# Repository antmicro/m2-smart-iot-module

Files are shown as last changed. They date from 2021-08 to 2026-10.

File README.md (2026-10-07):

# M.2 Smart IoT Module

Copyright (c) 2020-2026 [Antmicro](https://www.antmicro.com)

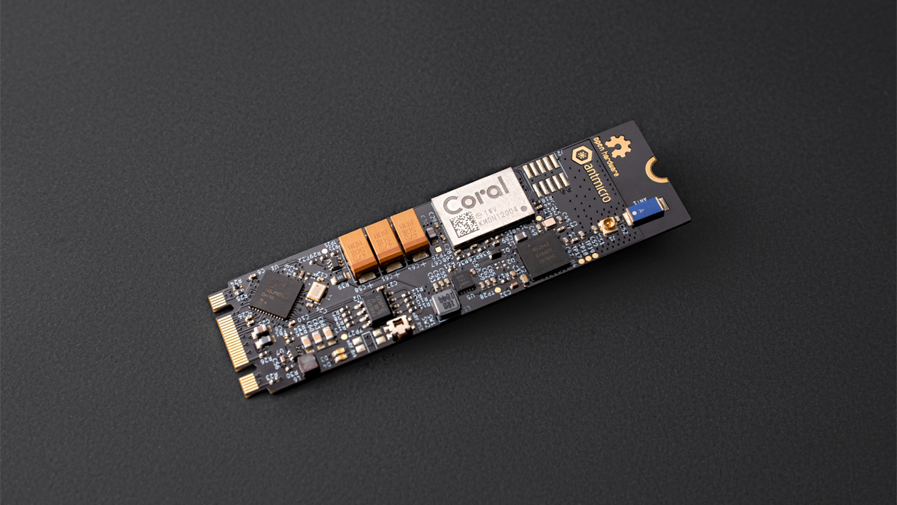
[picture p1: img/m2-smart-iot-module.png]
M.2 Smart IoT Module


## Overview

This project contains PCB design files of the smart IoT module in an M.2 form factor.
The module is an experimental platform that combines a programmable Nordic radio SoC with Google Coral Edge AI accelerator.
The design files were prepared in KiCad.

## Repository structure

The main repository directory contains KiCad PCB project files, a LICENSE and a README.
The remaining files are stored in the following directories:

* ``lib`` - contains the component libraries
* ``img`` - contains graphics for this README
* ``fab`` - contains overrides for board visualization

## Key Features

* Google Coral Edge TPU Accelerator Module
* Nordic Semiconductor nRF52840 Radio SoC
* On-board PCIe-USB bridge
* On-board FTDI chip for nRF52840 programming, debugging and serial communication
* M.2 key B+M form factor 
* 22 x 80 mm (0.87 x 3.15 inch) PCB outline

## License

[Apache-2.0](LICENSE)

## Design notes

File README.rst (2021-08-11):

====================
M.2 Smart IoT Module
====================

Copyright (c) 2020-2021 `Antmicro <https://www.antmicro.com>`_



Overview
--------

This repository contains design files of the smart IoT module in an M.2 form factor.
The module is an experimental platform that combines a programmable Nordic radio SoC with Google Coral Edge AI accelerator.
The design files were prepared in KiCad.
An initial production release for the design was fabricated as prototypes and these are now being tested.

Repository structure
--------------------
The main repository directory contains KiCad PCB project files, a LICENSE and README.
The remaining files are stored in the following directories:

* ``lib`` - contains the component libraries
* ``img`` - contains graphics for this README

Key Features
------------

* M.2 key B+M form factor 
* on-board PCIe-USB bridge
* Nordic Semiconductor nRF52840 Radio SoC
* Google Coral Edge TPU Accelerator Module

Block diagram
-------------

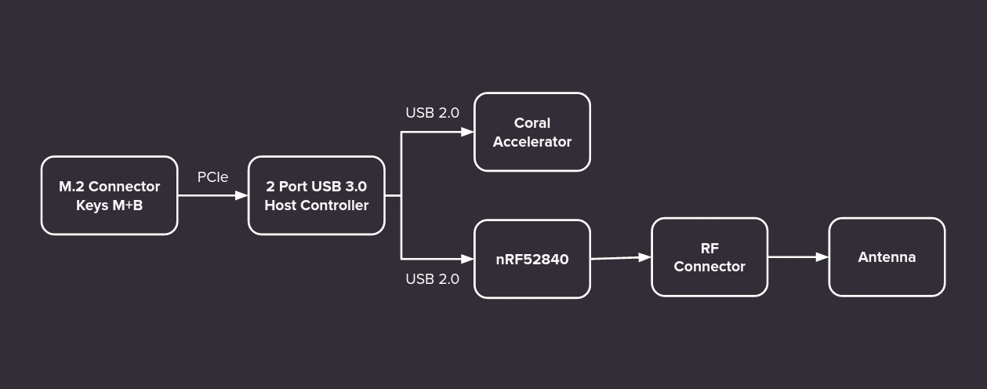
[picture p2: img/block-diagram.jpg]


License
=======

`Apache-2.0 <LICENSE>`_

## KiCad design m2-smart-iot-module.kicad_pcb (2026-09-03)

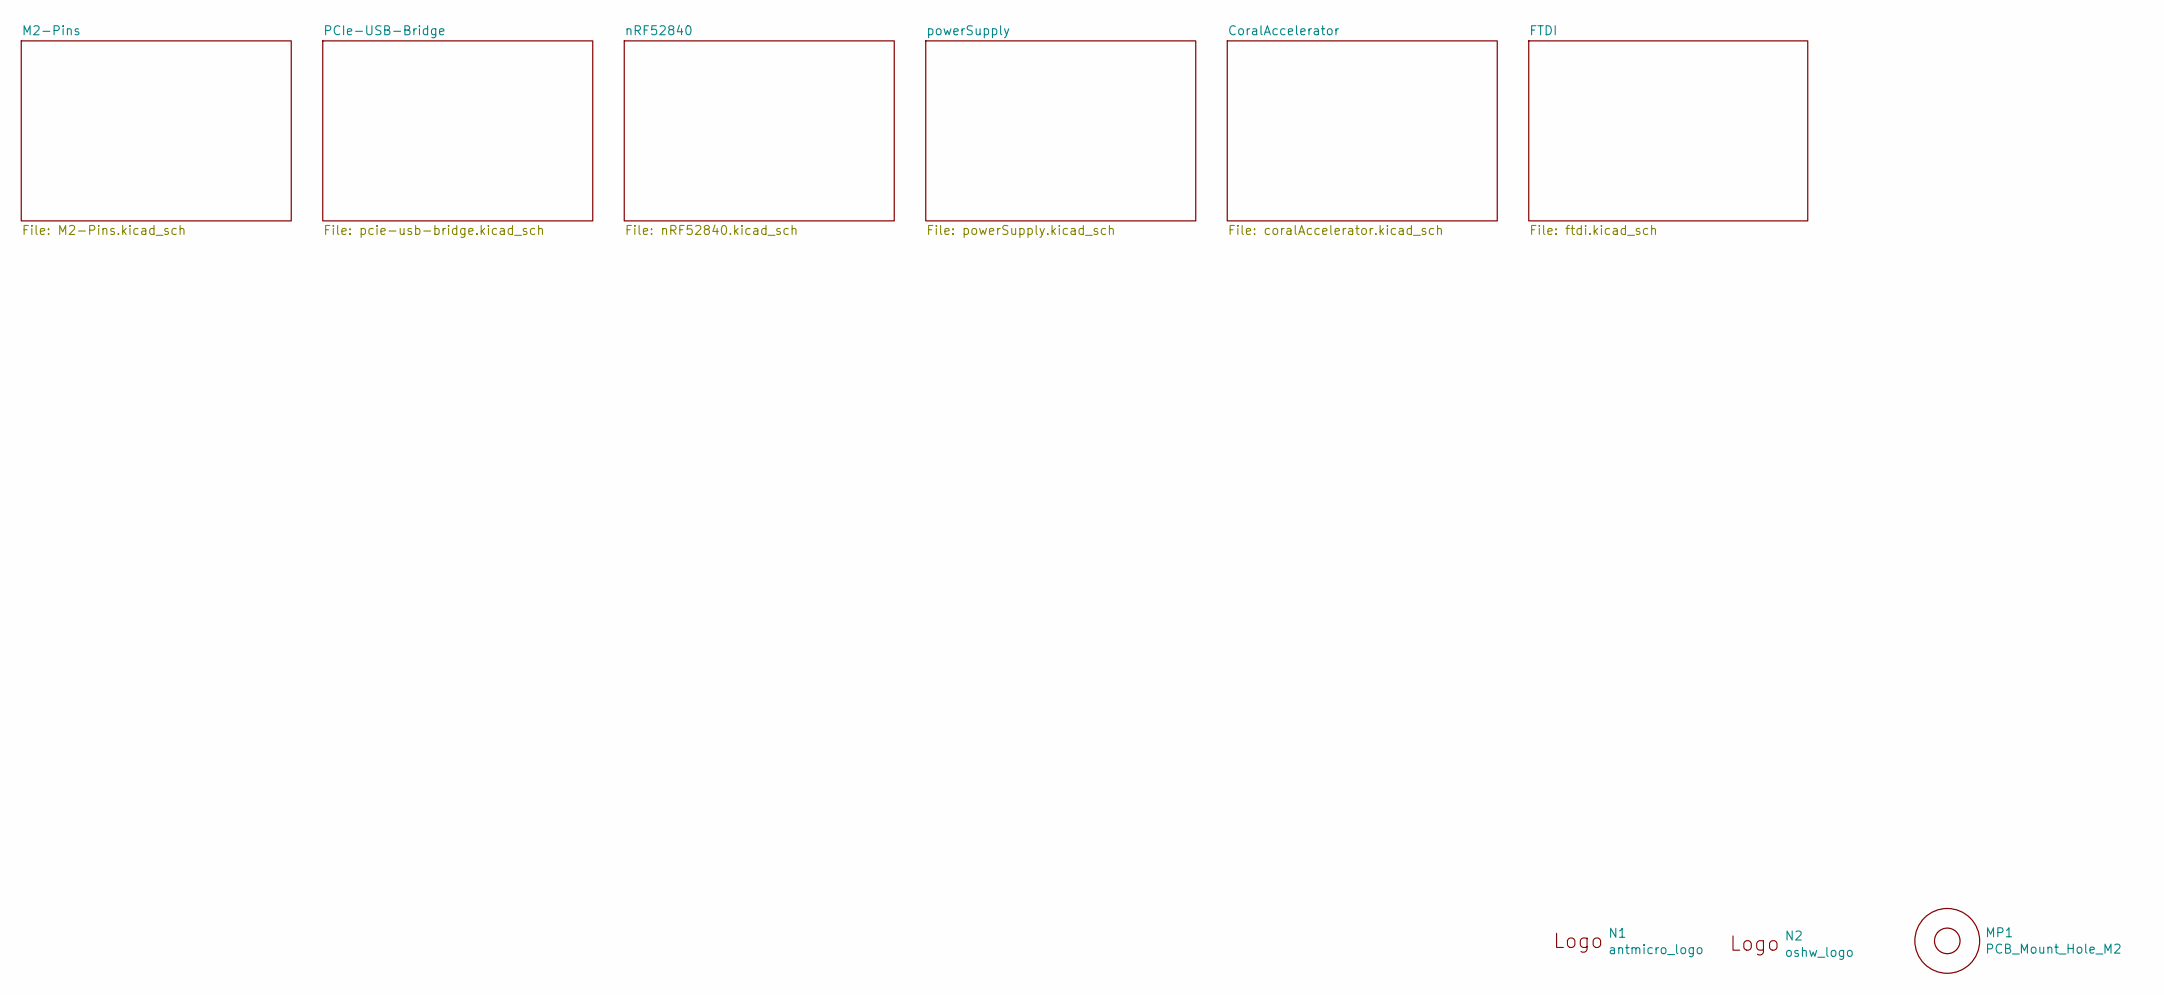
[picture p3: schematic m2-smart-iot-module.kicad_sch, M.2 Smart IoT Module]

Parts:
MP1: PCB_Mount_Hole_M2; M.2-Stud
N1: antmicro_logo; antmicro-logo_scaled_12mm
N2: oshw_logo; OSHW-Logo2_7.3x6mm_Copper_Mask

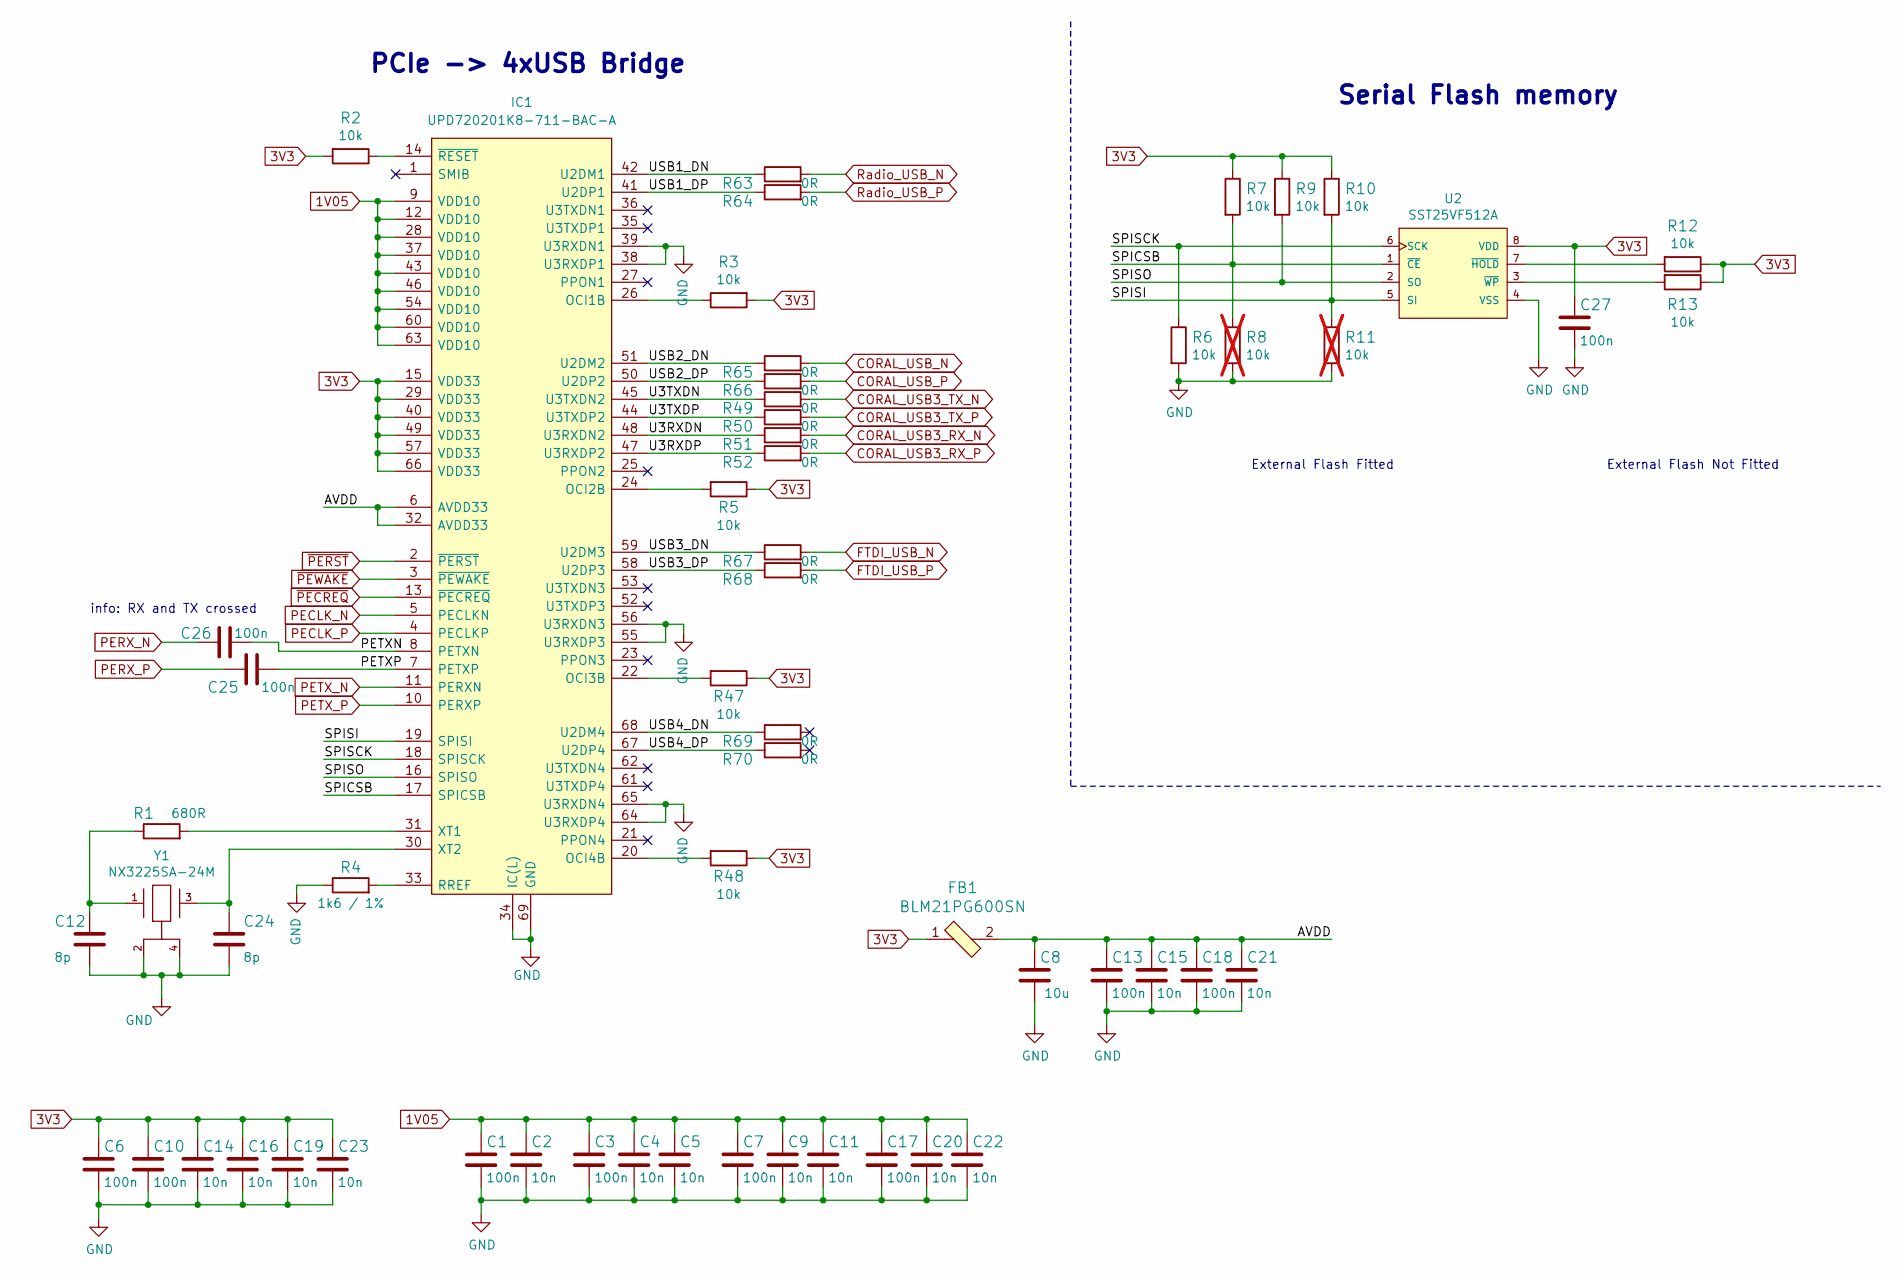
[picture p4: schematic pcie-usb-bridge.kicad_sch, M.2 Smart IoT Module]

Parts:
C1, C3, C6, C7, C10, C13, C17, C18, C25, C26, C27: C_100n_0402; 0402-cap; MPN GRM155R61H104KE14D
C2, C4, C5, C9, C11, C14, C15, C16, C19, C20, C21, C22, C23: C_10n_0402; 0402-cap; MPN 04025G103ZAT2A
C8: C_10u_0805; 0805-cap; MPN 160R15X106KV4E
C12, C24: C_8p_0402; 0402-cap; MPN CGA2B2C0G1H080D050BA
FB1: BLM21PG600SN; 0805-res; MPN BLM21PG600SN1
IC1: UPD720201K8-711-BAC-A; QFN40P800X800X90-69N-D; MPN UPD720201K8-711-BAC-A
R1: R_680R_0402; 0402-res; MPN MCWR04X6800FTL
R2, R3, R5, R6, R7, R9, R10, R12, R13: R_10k_0402; 0402-res; MPN CRCW040210K0FKEDHP
R4: R_1k6_0402; 0402-res; MPN MCWR04X1601FTL
R8, R11: R_10k_0402; 0402-res; MPN CRCW040210K0FKEDHP; not fitted
R47, R48: 0402-res; MPN CRCW040210K0FKEDHP
R49, R50, R51, R52, R63, R64, R65, R66, R67, R68, R69, R70: R_0R_0402; 0402-res; MPN ERJ2GE0R00X
U2: SST25VF512A; SOIC8-SST25VF512A-33-4I-SAE-Level_B; MPN SST25VF512A-33-4I-SAE
Y1: NX3225SA-24M; NDK-NX3225SA-0-0-MFG; MPN NX3225SA-24.000M-STD-CSR-3

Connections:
1V05: C1.1, C2.1, C3.1, C4.1, C5.1, C7.1, C9.1, C11.1, C17.1, C20.1, C22.1, IC1.9 (VDD10), IC1.12 (VDD10), IC1.28 (VDD10), IC1.37 (VDD10), IC1.43 (VDD10), IC1.46 (VDD10), IC1.54 (VDD10), IC1.60 (VDD10), IC1.63 (VDD10); also elsewhere on the board
3V3: C6.1, C10.1, C14.1, C16.1, C19.1, C23.1, C27.1, FB1.1, IC1.15 (VDD33), IC1.29 (VDD33), IC1.40 (VDD33), IC1.49 (VDD33), IC1.57 (VDD33), IC1.66 (VDD33), R2.2, R3.2, R5.1, R7.1, R9.1, R10.1, R12.1, R13.1, R47.1, R48.1, U2.8 (VDD); also elsewhere on the board
/PCIe-USB-Bridge/AVDD: C8.1, C13.1, C15.1, C18.1, C21.1, FB1.2, IC1.6 (AVDD33), IC1.32 (AVDD33)
/PCIe-USB-Bridge/PETXN: C26.1, IC1.8 (PETXN)
/PCIe-USB-Bridge/PETXP: C25.1, IC1.7 (PETXP)
/PCIe-USB-Bridge/SPICSB: IC1.17 (SPICSB), R7.2, R8.1, U2.1 (~CE)
/PCIe-USB-Bridge/SPISCK: IC1.18 (SPISCK), R6.1, U2.6 (SCK)
/PCIe-USB-Bridge/SPISI: IC1.19 (SPISI), R10.2, R11.1, U2.5 (SI)
/PCIe-USB-Bridge/SPISO: IC1.16 (SPISO), R9.2, U2.2 (SO)
/PCIe-USB-Bridge/U3RXDN: IC1.48 (U3RXDN2), R51.1
/PCIe-USB-Bridge/U3RXDP: IC1.47 (U3RXDP2), R52.1
/PCIe-USB-Bridge/U3TXDN: IC1.45 (U3TXDN2), R49.1
/PCIe-USB-Bridge/U3TXDP: IC1.44 (U3TXDP2), R50.1
/PCIe-USB-Bridge/USB1_DN: IC1.42 (U2DM1), R63.1
/PCIe-USB-Bridge/USB1_DP: IC1.41 (U2DP1), R64.1
/PCIe-USB-Bridge/USB2_DN: IC1.51 (U2DM2), R65.1
/PCIe-USB-Bridge/USB2_DP: IC1.50 (U2DP2), R66.1
/PCIe-USB-Bridge/USB3_DN: IC1.59 (U2DM3), R67.1
/PCIe-USB-Bridge/USB3_DP: IC1.58 (U2DP3), R68.1
/PCIe-USB-Bridge/USB4_DN: IC1.68 (U2DM4), R69.1
/PCIe-USB-Bridge/USB4_DP: IC1.67 (U2DP4), R70.1
CORAL_USB3_RX_N: R51.2
CORAL_USB3_RX_P: R52.2
CORAL_USB3_TX_N: R49.2
CORAL_USB3_TX_P: R50.2
CORAL_USB_N: R65.2; also elsewhere on the board
CORAL_USB_P: R66.2; also elsewhere on the board
FTDI_USB_N: R67.2; also elsewhere on the board
FTDI_USB_P: R68.2; also elsewhere on the board
GND: C1.2, C2.2, C3.2, C4.2, C5.2, C6.2, C7.2, C8.2, C9.2, C10.2, C11.2, C12.2, C13.2, C14.2, C15.2, C16.2, C17.2, C18.2, C19.2, C20.2, C21.2, C22.2, C23.2, C24.2, C27.2, IC1.34 (IC(L)), IC1.38 (U3RXDP1), IC1.39 (U3RXDN1), IC1.55 (U3RXDP3), IC1.56 (U3RXDN3), IC1.64 (U3RXDP4), IC1.65 (U3RXDN4), IC1.69 (GND), R4.1, R6.2, R8.2, R11.2, U2.4 (VSS), Y1.2 (GND), Y1.4 (GND); also elsewhere on the board
unnamed: C12.1, R1.1, Y1.1
unnamed: C24.1, IC1.30 (XT2), Y1.3
unnamed: IC1.14 (~RESET), R2.1
unnamed: IC1.20 (OCI4B), R48.2
unnamed: IC1.22 (OCI3B), R47.2
unnamed: IC1.24 (OCI2B), R5.2
unnamed: IC1.26 (OCI1B), R3.1
unnamed: IC1.31 (XT1), R1.2
unnamed: IC1.33 (RREF), R4.2
unnamed: R12.2, U2.7 (~HOLD)
unnamed: R13.2, U2.3 (~WP)
PECLK_N: IC1.5 (PECLKN); also elsewhere on the board
PECLK_P: IC1.4 (PECLKP); also elsewhere on the board
PERX_N: C26.2; also elsewhere on the board
PERX_P: C25.2; also elsewhere on the board
PETX_N: IC1.11 (PERXN); also elsewhere on the board
PETX_P: IC1.10 (PERXP); also elsewhere on the board
Radio_USB_N: R63.2; also elsewhere on the board
Radio_USB_P: R64.2; also elsewhere on the board
~PECREQ: IC1.13 (~PECREQ); also elsewhere on the board
~PERST: IC1.2 (~PERST); also elsewhere on the board
~PEWAKE: IC1.3 (~PEWAKE); also elsewhere on the board

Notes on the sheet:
Serial Flash memory
External Flash Not Fitted
PCIe -> 4xUSB Bridge
External Flash Fitted
info: RX and TX crossed

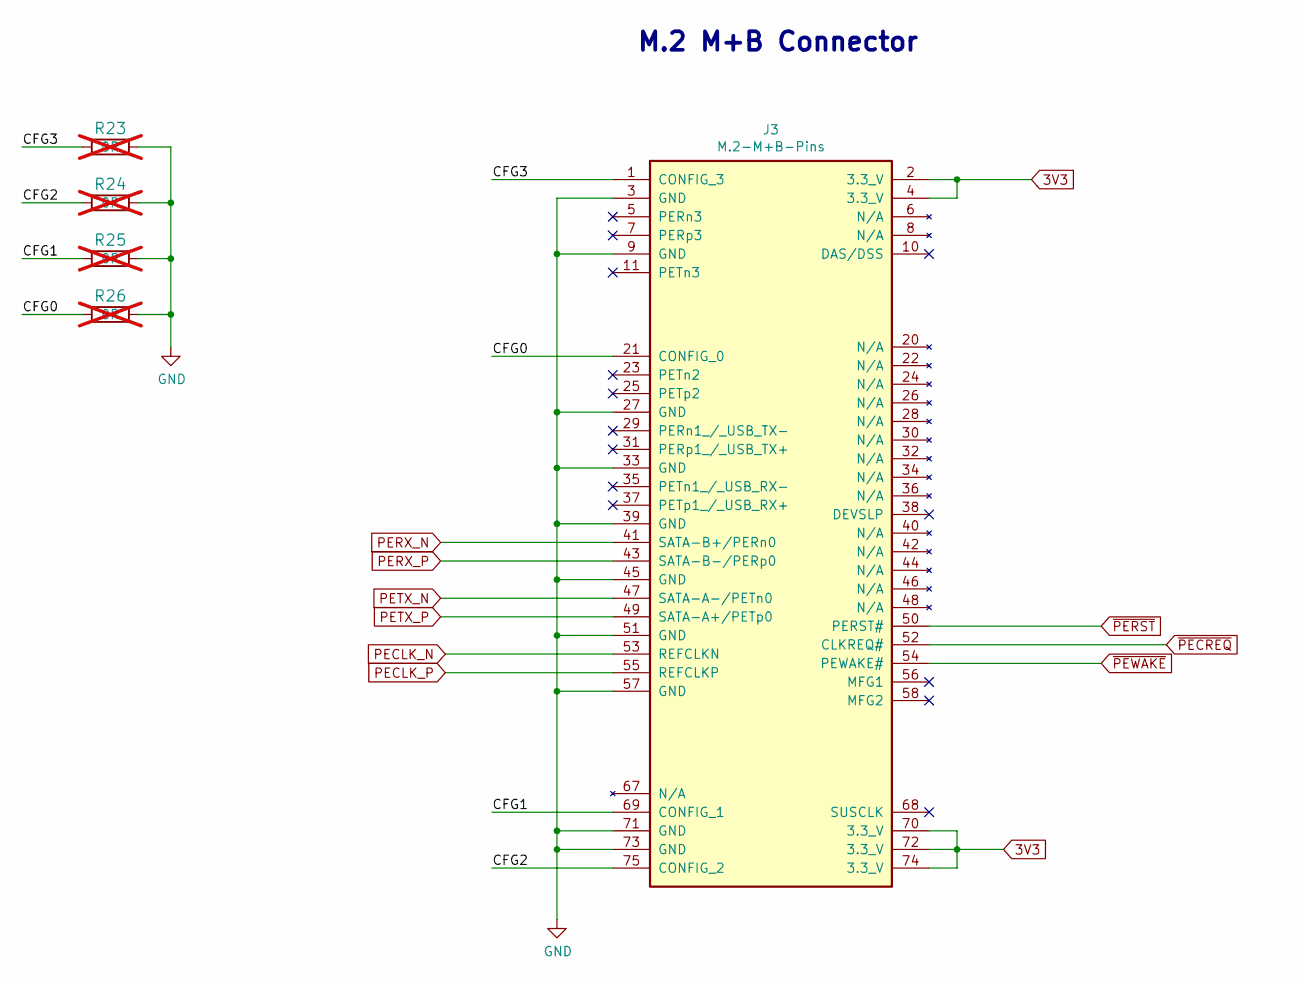
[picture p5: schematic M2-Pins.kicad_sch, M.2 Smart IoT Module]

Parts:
J3: M.2-M+B-Pins; M.2-M+B-Keys
R23, R24, R25, R26: R_0R_0402; 0402-res; MPN ERJ2GE0R00X; not fitted

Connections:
3V3: J3.2 (3.3_V), J3.4 (3.3_V), J3.70 (3.3_V), J3.72 (3.3_V), J3.74 (3.3_V); also elsewhere on the board
/M2-Pins/CFG0: J3.21 (CONFIG_0), R26.1
/M2-Pins/CFG1: J3.69 (CONFIG_1), R25.1
/M2-Pins/CFG2: J3.75 (CONFIG_2), R24.1
/M2-Pins/CFG3: J3.1 (CONFIG_3), R23.1
GND: J3.3 (GND), J3.9 (GND), J3.27 (GND), J3.33 (GND), J3.39 (GND), J3.45 (GND), J3.51 (GND), J3.57 (GND), J3.71 (GND), J3.73 (GND), R23.2, R24.2, R25.2, R26.2; also elsewhere on the board
PECLK_N: J3.53 (REFCLKN); also elsewhere on the board
PECLK_P: J3.55 (REFCLKP); also elsewhere on the board
PERX_N: J3.41 (SATA-B+/PERn0); also elsewhere on the board
PERX_P: J3.43 (SATA-B-/PERp0); also elsewhere on the board
PETX_N: J3.47 (SATA-A-/PETn0); also elsewhere on the board
PETX_P: J3.49 (SATA-A+/PETp0); also elsewhere on the board
~PECREQ: J3.52 (CLKREQ#); also elsewhere on the board
~PERST: J3.50 (PERST#); also elsewhere on the board
~PEWAKE: J3.54 (PEWAKE#); also elsewhere on the board

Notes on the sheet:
M.2 M+B Connector

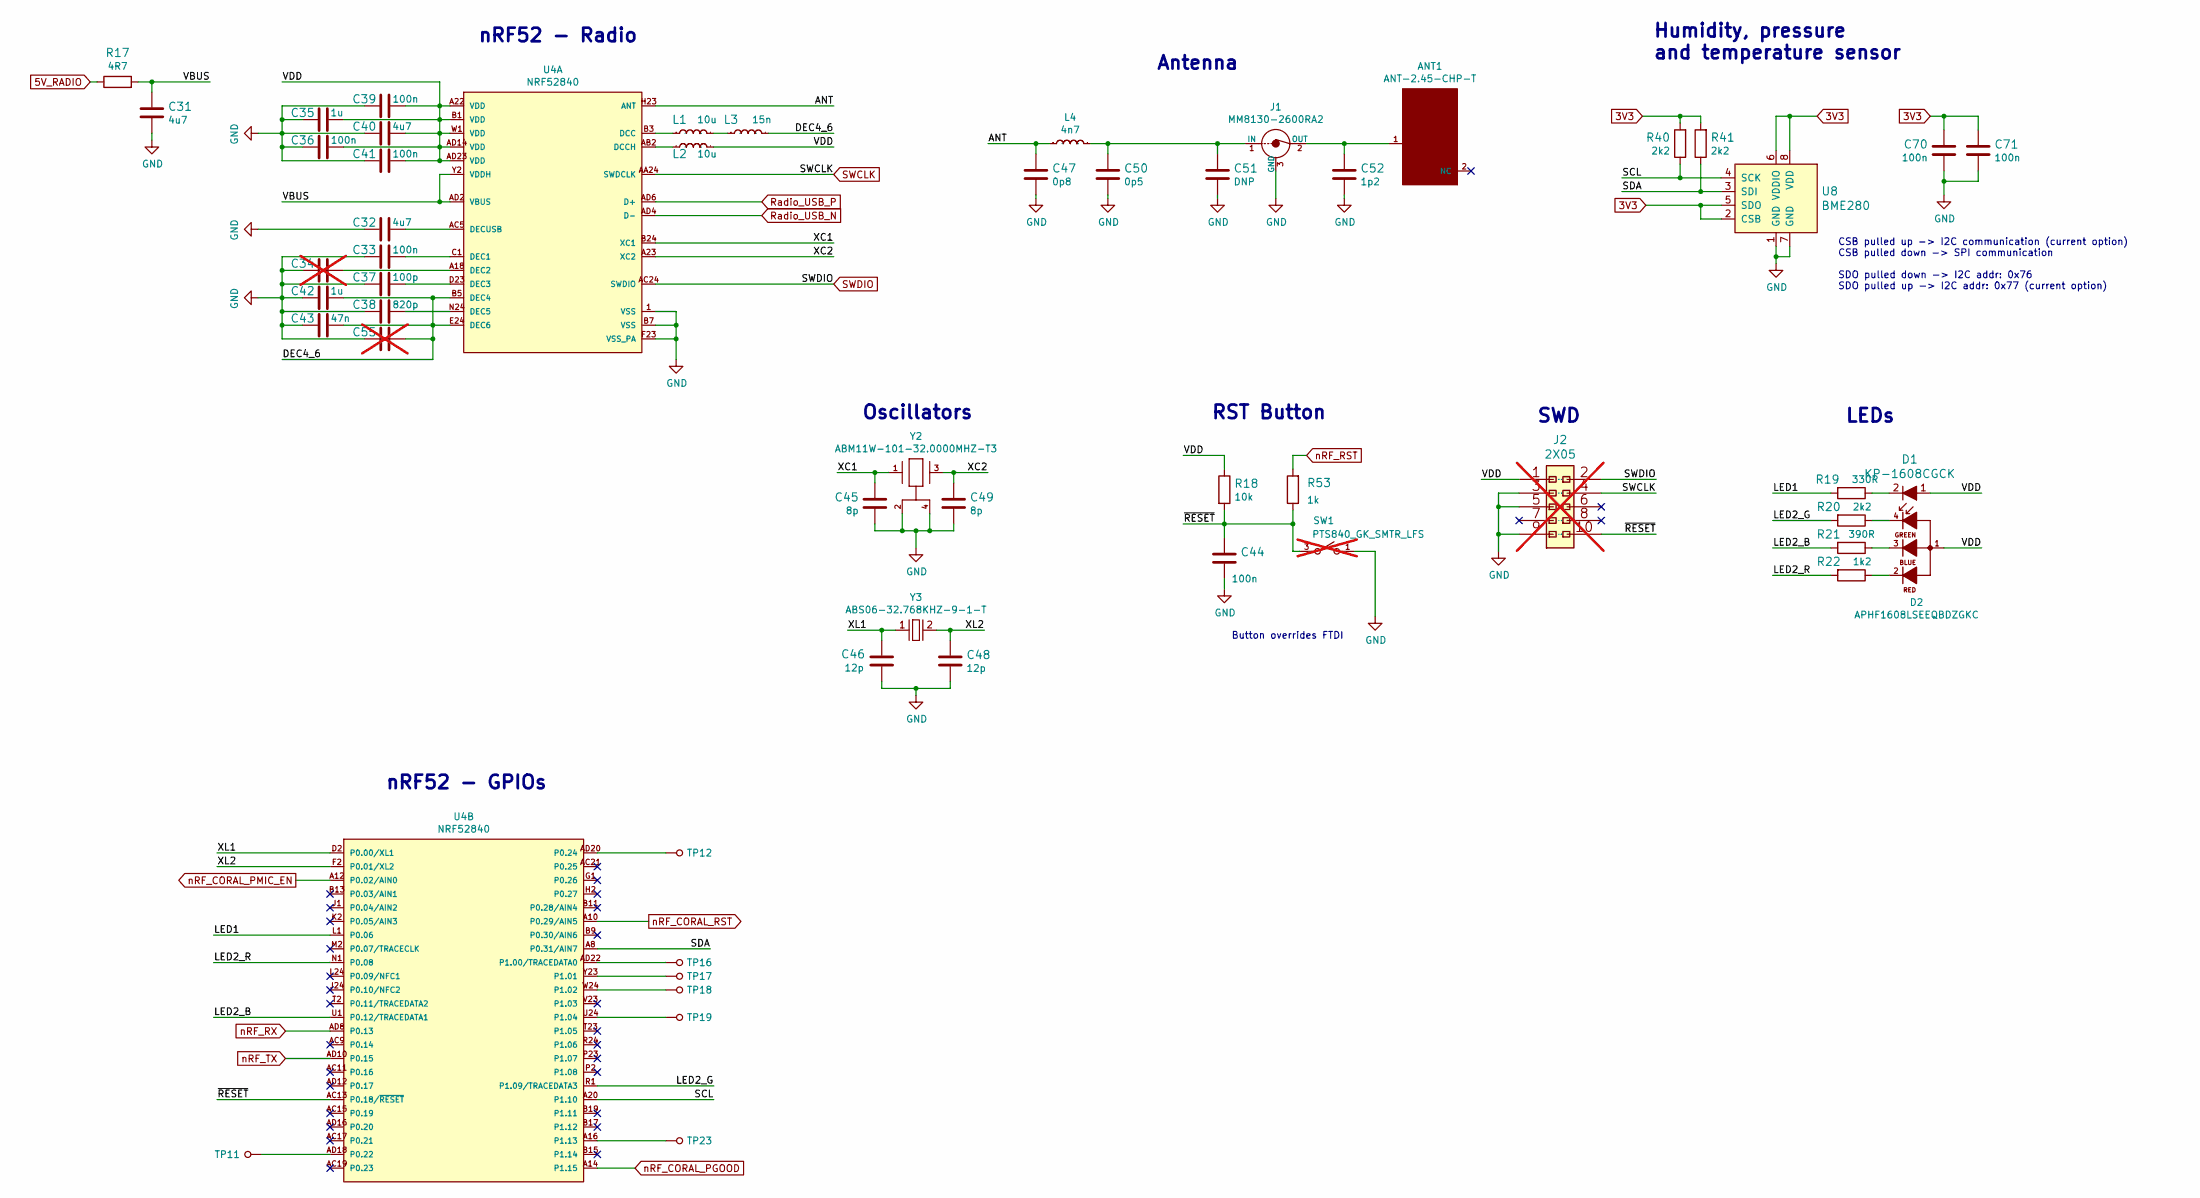
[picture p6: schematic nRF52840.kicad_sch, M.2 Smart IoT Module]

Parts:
ANT1: ANT-2.45-CHP-T; Linx-ANT-2.45-CHP-T-MFG; MPN ANT-2.45-CHP-T
C31, C32, C40: C_4u7_0402; 0402-cap; MPN GRM155R61A475MEAAD
C33, C36, C39, C41, C44, C70, C71: C_100n_0402; 0402-cap; MPN GRM155R61H104KE14D
C34, C55: C_100n_0402; 0402-cap; MPN 0402X104K6R3CT; not fitted
C35, C42: C_1u_0402; 0402-cap; MPN C1005X6S1A105K050BC
C37: C_100p_0402; 0402-cap; MPN 0402N101J500CT
C38: C_820p_0402; 0402-cap; MPN CGA2B2C0G1H821J050BA
C43: C_47n_0402; 0402-cap; MPN MC0402X473K160CT
C45, C49: C_8p_0402; 0402-cap; MPN CGA2B2C0G1H080D050BA
C46, C48: C_12p_0402; 0402-cap; MPN CGA2B2C0G1H120J050BA
C47: C_0p8_0402; 0402-cap; MPN GJM1555C1HR80WB01D
C50: C_0p5_0402; 0402-cap; MPN GJM1555C1HR50WB01D
C51: RF_Capacitor; 0402-cap
C52: C_1p2_0402; 0402-cap; MPN GJM1555C1H1R2WB01D
D1: KP-1608CGCK; LED0603; MPN KP-1608CGCK
D2: APHF1608LSEEQBDZGKC; LED_APHF1608LSEEQBDZGKC; MPN APHF1608LSEEQBDZGKC
J1: MM8130-2600RA2; Murata-MM8130-2600RA2-MFG; MPN MM8130-2600RA2
J2: 2X05; ARM_SWD; MPN SHF-105-01-L-D-SM; not fitted
L1: L_10u_250mA_0603; 0603-res; MPN MLZ1608M100WTD25
L2: L_10u_80mA_0603; 0603-res; MPN LBMF1608T100K
L3: L_15n_0402; 0402-res; MPN HK100515NJ-T
L4: L_4n7_0402; 0402-res; MPN MCFT000004
R17: R_4R7_0402; 0402-res; MPN ERJ2GEJ4R7X
R18: R_10k_0402; 0402-res; MPN CRCW040210K0FKEDHP
R19: R_330R_0402; 0402-res; MPN ERJ2RKF3300X
R20, R40, R41: R_2k2_0402; 0402-res; MPN RC0402FR-072K2L
R21: R_390R_0402; 0402-res; MPN ERJ2RKF3900X
R22: R_1k2_0402; 0402-res; MPN ERJ2RKF1201X
R53: R_1k_0402; 0402-res; MPN CR0402-FX-1001GLF
SW1: PTS840_GK_SMTR_LFS; CK-PTS840_GK_SMTR_LFS-0; MPN PTS840 GK SMTR LFS; not fitted
TP11, TP12, TP16, TP17, TP18, TP19, TP23: TP_SMD1MM; Testpoint_smd_1mm
U4: NRF52840; Nordic_Semiconductor-NRF52840-QIAA-R-0-0-MFG; MPN NRF52840-QIAA-R
U8: BME280; Pressure_Sensor_LGA-8_2.5x2.5mm_BME280; MPN BME280
Y2: ABM11W-101-32.0000MHZ-T3; Abracon-ABM11W-0-0-0; MPN ABM11W-101-32.0000MHZ-T3
Y3: ABS06-32.768KHZ-9-1-T; Abracon-ABS06-32.768KHZ-T-0; MPN ABS06-32.768KHZ-9-1-T

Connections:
3V3: C70.2, C71.1, R40.2, R41.2, U8.2 (CSB), U8.5 (SDO), U8.6 (VDDIO), U8.8 (VDD); also elsewhere on the board
5V_RADIO: R17.1; also elsewhere on the board
/nRF52840/ANT: C47.1, L4.1, U4.H23 (ANT)
/nRF52840/DEC4_6: C42.1, C43.1, C55.1, L3.2, U4.B5 (DEC4), U4.E24 (DEC6)
/nRF52840/LED1: R19.2, U4.L1 (P0.06)
/nRF52840/LED2_B: R21.2, U4.U1 (P0.12/TRACEDATA1)
/nRF52840/LED2_G: R20.2, U4.R1 (P1.09/TRACEDATA3)
/nRF52840/LED2_R: R22.2, U4.N1 (P0.08)
/nRF52840/SCL: R40.1, U4.A20 (P1.10), U8.4 (SCK)
/nRF52840/SDA: R41.1, U4.A8 (P0.31/AIN7), U8.3 (SDI)
/nRF52840/VBUS: C31.1, R17.2, U4.AD2 (VBUS), U4.Y2 (VDDH)
/nRF52840/VDD: C35.1, C36.1, C39.1, C40.1, C41.1, D1.1, D2.1, J2.1, L2.2, R18.1, U4.A22 (VDD), U4.AD14 (VDD), U4.AD23 (VDD), U4.B1 (VDD), U4.W1 (VDD)
/nRF52840/XC1: C45.1, U4.B24 (XC1), Y2.1
/nRF52840/XC2: C49.1, U4.A23 (XC2), Y2.3
/nRF52840/XL1: C46.1, U4.D2 (P0.00/XL1), Y3.1
/nRF52840/XL2: C48.1, U4.F2 (P0.01/XL2), Y3.2
/nRF52840/~RESET: C44.1, J2.10, R18.2, R53.1, SW1.3, SW1.4, U4.AC13 (P0.18/~RESET)
GND: C31.2, C32.2, C33.2, C34.2, C35.2, C36.2, C37.2, C38.2, C39.2, C40.2, C41.2, C42.2, C43.2, C44.2, C45.2, C46.2, C47.2, C48.2, C49.2, C50.2, C51.2, C52.2, C55.2, C70.1, C71.2, J1.3 (GND), J1.4 (GND), J1.5 (GND), J1.6 (GND), J2.3, J2.5, J2.9, SW1.1, SW1.2, U4.1 (VSS), U4.B7 (VSS), U4.F23 (VSS_PA), U8.1 (GND), U8.7 (GND), Y2.2 (GND), Y2.4 (GND); also elsewhere on the board
unnamed: ANT1.1 (FEED), C52.1, J1.2 (OUT)
unnamed: C32.1, U4.AC5 (DECUSB)
unnamed: C33.1, U4.C1 (DEC1)
unnamed: C34.1, U4.A18 (DEC2)
unnamed: C37.1, U4.D23 (DEC3)
unnamed: C38.1, U4.N24 (DEC5)
unnamed: C50.1, C51.1, J1.1 (IN), L4.2
unnamed: D1.2, R19.1
unnamed: D2.2, R22.1
unnamed: D2.3, R21.1
unnamed: D2.4, R20.1
unnamed: L1.1, U4.B3 (DCC)
unnamed: L1.2, L3.1
unnamed: L2.1, U4.AB2 (DCCH)
unnamed: TP11.1, U4.AD18 (P0.22)
unnamed: TP12.1, U4.AD20 (P0.24)
unnamed: TP16.1, U4.AD22 (P1.00/TRACEDATA0)
unnamed: TP17.1, U4.Y23 (P1.01)
unnamed: TP18.1, U4.W24 (P1.02)
unnamed: TP19.1, U4.U24 (P1.04)
unnamed: TP23.1, U4.A16 (P1.13)
Radio_USB_N: U4.AD4 (D-); also elsewhere on the board
Radio_USB_P: U4.AD6 (D+); also elsewhere on the board
SWCLK: J2.4, U4.AA24 (SWDCLK); also elsewhere on the board
SWDIO: J2.2, U4.AC24 (SWDIO); also elsewhere on the board
nRF_CORAL_PGOOD: U4.A14 (P1.15); also elsewhere on the board
nRF_CORAL_PMIC_EN: U4.A12 (P0.02/AIN0); also elsewhere on the board
nRF_CORAL_RST: U4.A10 (P0.29/AIN5); also elsewhere on the board
nRF_RST: R53.2; also elsewhere on the board
nRF_RX: U4.AD8 (P0.13); also elsewhere on the board
nRF_TX: U4.AD10 (P0.15); also elsewhere on the board

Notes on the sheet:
Button overrides FTDI
CSB pulled up -> I2C communication (current option) CSB pulled down -> SPI communication SDO pulled down -> I2C addr: 0x76 SDO pulled up -> I2C addr: 0x77 (current option)
Antenna
Oscillators
nRF52 - GPIOs
LEDs
RST Button
nRF52 - Radio
Humidity, pressure and temperature sensor
SWD

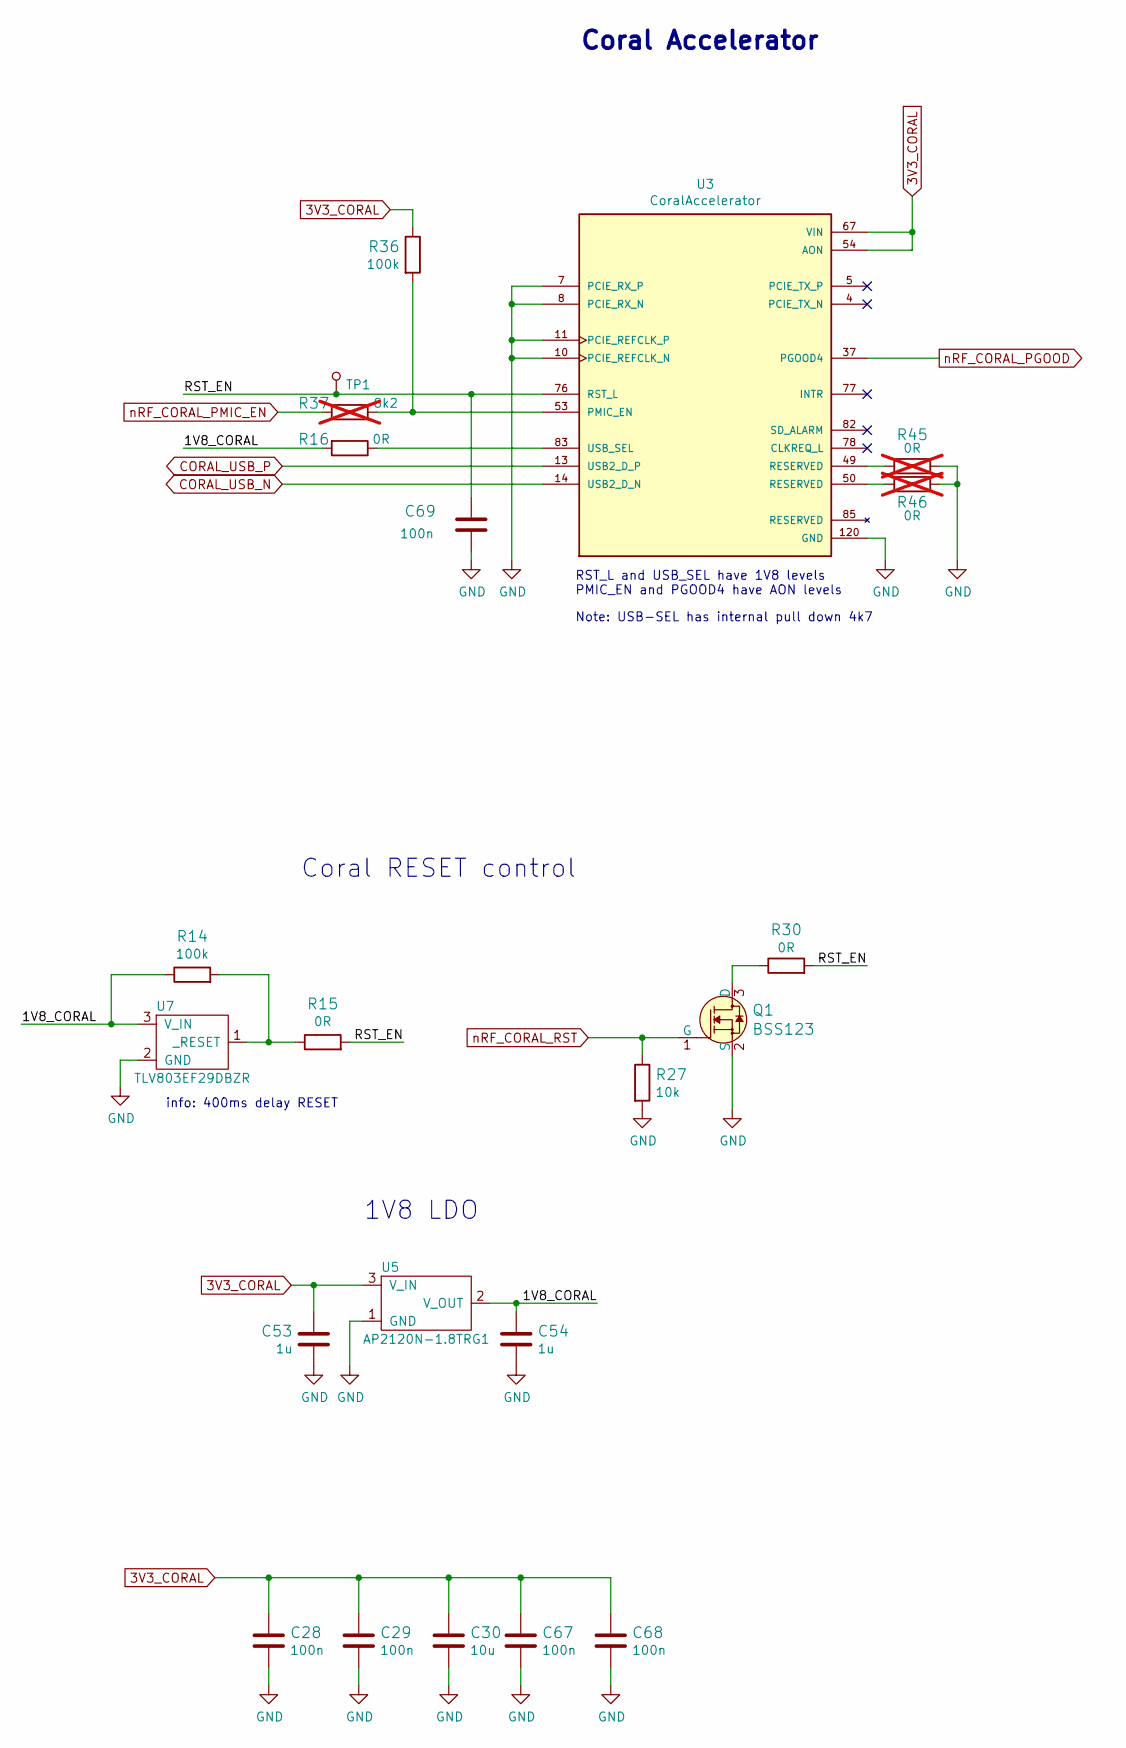
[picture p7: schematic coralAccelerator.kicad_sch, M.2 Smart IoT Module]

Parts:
C28, C29, C67, C68, C69: C_100n_0402; 0402-cap; MPN GRM155R61H104KE14D
C30: C_10u_0805; 0805-cap; MPN 160R15X106KV4E
C53, C54: C_1u_0402; 0402-cap; MPN C1005X6S1A105K050BC
Q1: BSS123; SOT-23-3; MPN BSS123
R14, R36: R_100k_0402; 0402-res; MPN CRCW0402100KFKEDHP
R15, R16, R30: R_0R_0402; 0402-res; MPN ERJ2GE0R00X
R27: R_10k_0402; 0402-res; MPN CRCW040210K0FKEDHP
R37: R_8k2_0402; 0402-res; MPN ERJ2RKF8201X; not fitted
R45, R46: R_0R_0402; 0402-res; MPN ERJ2GE0R00X; not fitted
TP1: TP_SMD1MM; Testpoint_smd_1mm
U3: CoralAccelerator; MODULE_G313-06329-00; MPN G313-06329-00
U5: AP2120N-1.8TRG1; SOT-23-3; MPN AP2120N-1.8TRG1
U7: TLV803EF29DBZR; SOT-23-3; MPN TLV803EF29DBZR

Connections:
3V3_CORAL: C28.1, C29.1, C30.1, C53.1, C67.1, C68.1, R36.1, U3.54 (AON), U3.56 (VIN), U3.57 (VIN), U3.58 (VIN), U3.59 (VIN), U3.60 (VIN), U3.61 (VIN), U3.62 (VIN), U3.63 (VIN), U3.64 (VIN), U3.65 (VIN), U3.66 (VIN), U3.67 (VIN), U5.3 (V_IN); also elsewhere on the board
/CoralAccelerator/1V8_CORAL: C54.1, R14.1, R16.2, U5.2 (V_OUT), U7.3 (V_IN)
/CoralAccelerator/RST_EN: C69.1, R15.2, R30.2, TP1.1, U3.76 (RST_L)
CORAL_USB_N: U3.14 (USB2_D_N); also elsewhere on the board
CORAL_USB_P: U3.13 (USB2_D_P); also elsewhere on the board
GND: C28.2, C29.2, C30.2, C53.2, C54.2, C67.2, C68.2, C69.2, Q1.2 (S), R27.2, R45.2, R46.2, U3.1 (GND), U3.2 (GND), U3.3 (GND), U3.6 (GND), U3.7 (PCIE_RX_P), U3.8 (PCIE_RX_N), U3.9 (GND), U3.10 (PCIE_REFCLK_N), U3.11 (PCIE_REFCLK_P), U3.12 (GND), U3.15 (GND), U3.16 (GND), U3.17 (GND), U3.18 (GND), U3.19 (GND), U3.20 (GND), U3.21 (GND), U3.22 (GND), U3.23 (GND), U3.24 (GND), U3.25 (GND), U3.26 (GND), U3.27 (GND), U3.28 (GND), U3.29 (GND), U3.30 (GND), U3.31 (GND), U3.32 (GND), U3.33 (GND), U3.34 (GND), U3.35 (GND), U3.36 (GND), U3.38 (GND), U3.39 (GND), U3.40 (GND), U3.41 (GND), U3.42 (GND), U3.43 (GND), U3.44 (GND), U3.45 (GND), U3.46 (GND), U3.47 (GND), U3.48 (GND), U3.51 (GND), U3.55 (GND), U3.68 (GND), U3.69 (GND), U3.70 (GND), U3.71 (GND), U3.72 (GND), U3.73 (GND), U3.74 (GND), U3.75 (GND), U3.79 (GND), U3.80 (GND), U3.81 (GND), U3.86 (GND), U3.87 (GND), U3.88 (GND), U3.89 (GND), U3.90 (GND), U3.91 (GND), U3.92 (GND), U3.93 (GND), U3.94 (GND), U3.95 (GND), U3.96 (GND), U3.97 (GND), U3.98 (GND), U3.99 (GND), U3.100 (GND), U3.101 (GND), U3.102 (GND), U3.103 (GND), U3.104 (GND), U3.105 (GND), U3.106 (GND), U3.107 (GND), U3.108 (GND), U3.109 (GND), U3.110 (GND), U3.111 (GND), U3.112 (GND), U3.113 (GND), U3.114 (GND), U3.115 (GND), U3.116 (GND), U3.117 (GND), U3.118 (GND), U3.119 (GND), U3.120 (GND), U5.1 (GND), U7.2 (GND); also elsewhere on the board
unnamed: Q1.3 (D), R30.1
unnamed: R14.2, R15.1, U7.1 (_RESET)
unnamed: R16.1, U3.83 (USB_SEL)
unnamed: R36.2, R37.1, U3.53 (PMIC_EN)
unnamed: R45.1, U3.49 (RESERVED)
unnamed: R46.1, U3.50 (RESERVED)
nRF_CORAL_PGOOD: U3.37 (PGOOD4); also elsewhere on the board
nRF_CORAL_PMIC_EN: R37.2; also elsewhere on the board
nRF_CORAL_RST: Q1.1 (G), R27.1; also elsewhere on the board

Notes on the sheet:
RST_L and USB_SEL have 1V8 levels PMIC_EN and PGOOD4 have AON levels
Coral Accelerator
Coral RESET control
Note: USB-SEL has internal pull down 4k7
info: 400ms delay RESET
1V8 LDO

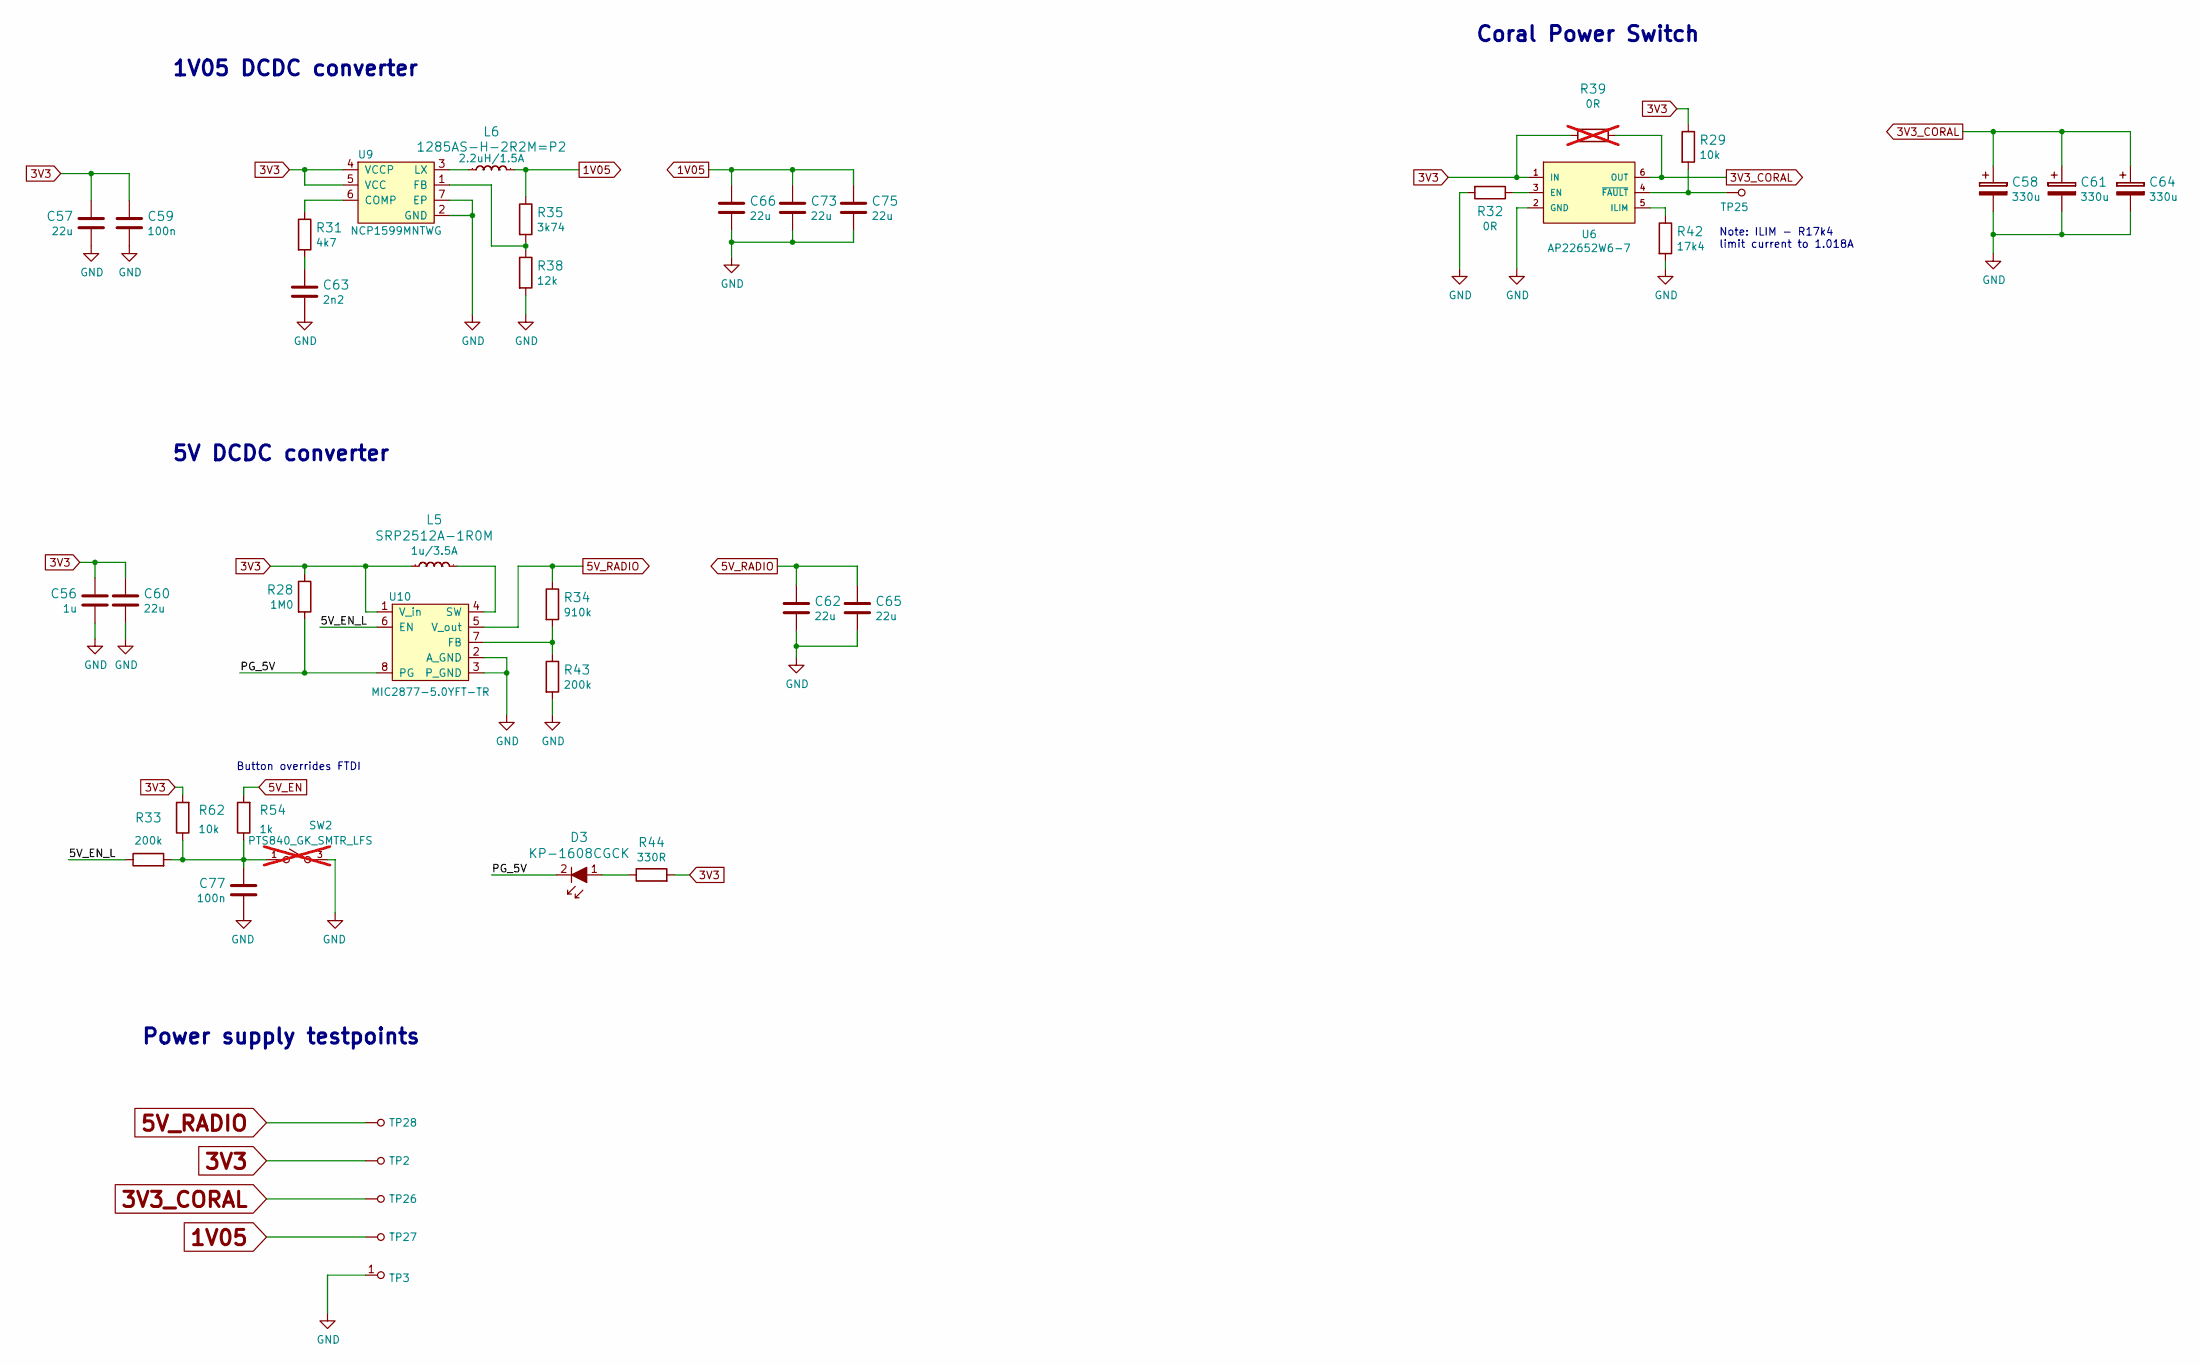
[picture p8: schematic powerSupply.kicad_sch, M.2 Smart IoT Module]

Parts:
C56: C_1u_0402; 0402-cap; MPN C1005X6S1A105K050BC
C57: C_22u_0603; 0603-cap; MPN GRM188R60J226MEA0D
C58, C61, C64: C_330u_EEF-SX; Panasonic_Electronic_Components-CD-0-0-MFG; MPN EEF-SX0G331ER
C59, C77: C_100n_0402; 0402-cap; MPN GRM155R61H104KE14D
C60, C62, C65, C66, C73, C75: C_22u_0805_10V; 0805-cap; MPN 0805ZD226MAT2A
C63: C_2n2_0402; 0402-cap; MPN C0402C222J5RACTU
D3: KP-1608CGCK; LED0603; MPN KP-1608CGCK
L5: SRP2512A-1R0M; MPN SRP2512A-1R0M
L6: 1285AS-H-2R2M=P2; 0805-res; MPN 1285AS-H-2R2M=P2
R28: R_1M0_0402; 0402-res; MPN CRG0402F1M0
R29, R62: R_10k_0402; 0402-res; MPN CRCW040210K0FKEDHP
R31: R_4k7_0402; 0402-res; MPN MCS04020C4701FE000
R32: R_0R_0402; 0402-res; MPN ERJ2GE0R00X
R33, R43: R_200k_0402; 0402-res; MPN RC0402FR-07200KL
R34: R_910k_0402; 0402-res; MPN CRCW0402910KFKED
R35: R_3k74_0402; 0402-res; MPN MCWR04X3741FTL
R38: R_12k_0402; 0402-res; MPN CRCW040212K0FKEDHP
R39: R_0R_0805; 0805-res; MPN CRCW08050000Z0EA; not fitted
R42: R_17k4_0402; 0402-res; MPN RC0402FR-0717K4L
R44: R_330R_0402; 0402-res; MPN ERJ2RKF3300X
R54: R_1k_0402; 0402-res; MPN CR0402-FX-1001GLF
SW2: PTS840_GK_SMTR_LFS; CK-PTS840_GK_SMTR_LFS-0; MPN PTS840 GK SMTR LFS; not fitted
TP2, TP25, TP26, TP27, TP28: TP_SMD1MM; Testpoint_smd_1mm
TP3: TP; TP-R-1.5
U6: AP22652W6-7; SOT-23-6; MPN AP22652W6-7
U9: NCP1599MNTWG; DFN-6_3x3mm_EP1; MPN NCP1599MNTWG
U10: MIC2877-5.0YFT-TR; FTQFN; MPN MIC2877-5.0YFT-TR

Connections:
1V05: C66.1, C73.1, C75.1, L6.2, R35.1, TP27.1; also elsewhere on the board
3V3: C56.1, C57.1, C59.1, C60.1, L5.1, R28.1, R29.1, R39.1, R44.2, R62.2, TP2.1, U6.1 (IN), U9.4 (VCCP), U9.5 (VCC), U10.1 (V_in); also elsewhere on the board
3V3_CORAL: C58.1, C61.1, C64.1, R39.2, TP26.1, U6.6 (OUT); also elsewhere on the board
5V_EN: R54.2; also elsewhere on the board
5V_RADIO: C62.1, C65.1, R34.1, TP28.1, U10.5 (V_out); also elsewhere on the board
/powerSupply/5V_EN_L: R33.1, U10.6 (EN)
/powerSupply/PG_5V: D3.2, R28.2, U10.8 (PG)
GND: C56.2, C57.2, C58.2, C59.2, C60.2, C61.2, C62.2, C63.2, C64.2, C65.2, C66.2, C73.2, C75.2, C77.2, R32.2, R38.2, R42.2, R43.2, SW2.3, SW2.4, TP3.1, U6.2 (GND), U9.2 (GND), U9.7 (EP), U10.2 (A_GND), U10.3 (P_GND); also elsewhere on the board
unnamed: C63.1, R31.2
unnamed: C77.1, R33.2, R54.1, R62.1, SW2.1, SW2.2
unnamed: D3.1, R44.1
unnamed: L5.2, U10.4 (SW)
unnamed: L6.1, U9.3 (LX)
unnamed: R29.2, TP25.1, U6.4 (~FAULT)
unnamed: R31.1, U9.6 (COMP)
unnamed: R32.1, U6.3 (EN)
unnamed: R34.2, R43.1, U10.7 (FB)
unnamed: R35.2, R38.1, U9.1 (FB)
unnamed: R42.1, U6.5 (ILIM)

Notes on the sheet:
Button overrides FTDI
Note: ILIM - R17k4 limit current to 1.018A
Coral Power Switch
5V DCDC converter
Power supply testpoints
1V05 DCDC converter

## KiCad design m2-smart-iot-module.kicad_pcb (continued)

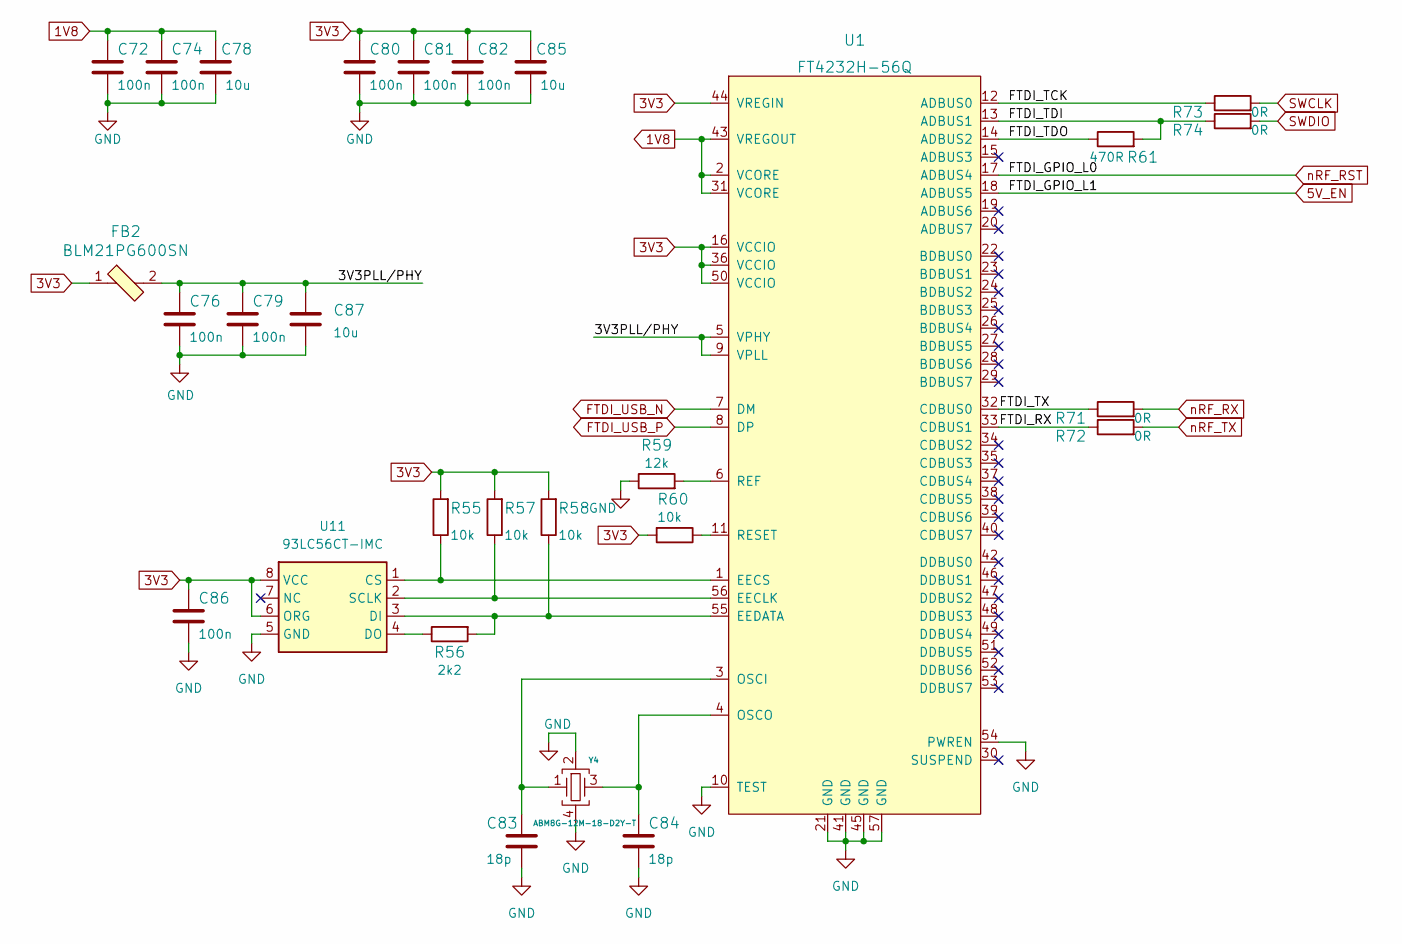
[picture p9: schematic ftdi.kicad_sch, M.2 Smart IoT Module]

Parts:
C72, C74, C76, C79, C80, C81, C82, C86: C_100n_0402; 0402-cap; MPN GRM155R61H104KE14D
C78, C85: C_10u_0805; 0805-cap; MPN 160R15X106KV4E
C83, C84: C_18p_0402; 0402-cap; MPN MC0402N180J500CT
C87: C_10u_0603; 0603-cap; MPN GRM188R61A106KE69D
FB2: BLM21PG600SN; 0805-res; MPN BLM21PG600SN1
R55, R57, R58, R60: R_10k_0402; 0402-res; MPN CRCW040210K0FKEDHP
R56: R_2k2_0402; 0402-res; MPN RC0402FR-072K2L
R59: R_12k_0402; 0402-res; MPN CRCW040212K0FKEDHP
R61: R_470R_0402; 0402-res; MPN CRCW0402470RFKED
R71, R72, R73, R74: R_0R_0402; 0402-res; MPN ERJ2GE0R00X
U1: FT4232H-56Q; QFN-56-1EP_8x8mm_P0.5mm_EP5.5.9x5.9mm; MPN FT4232H-56Q-REEL
U11: 93LC56CT-IMC; DFN-8_2x3mm; MPN 93LC56CT-IMC
Y4: ABM8G-12M-18-D2Y-T; KX-7; MPN ABM8G-12.000MHZ-18-D2Y-T

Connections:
1V8: C72.1, C74.1, C78.1, U1.2 (VCORE), U1.31 (VCORE), U1.43 (VREGOUT)
3V3: C80.1, C81.1, C82.1, C85.1, C86.1, FB2.1, R55.2, R57.2, R58.2, R60.2, U1.16 (VCCIO), U1.36 (VCCIO), U1.44 (VREGIN), U1.50 (VCCIO), U11.6 (ORG), U11.8 (VCC); also elsewhere on the board
5V_EN: U1.18 (ADBUS5); also elsewhere on the board
/FTDI/3V3PLL/PHY: C76.1, C79.1, C87.1, FB2.2, U1.5 (VPHY), U1.9 (VPLL)
/FTDI/FTDI_RX: R72.1, U1.33 (CDBUS1)
/FTDI/FTDI_TCK: R73.1, U1.12 (ADBUS0)
/FTDI/FTDI_TDI: R61.2, R74.1, U1.13 (ADBUS1)
/FTDI/FTDI_TDO: R61.1, U1.14 (ADBUS2)
/FTDI/FTDI_TX: R71.1, U1.32 (CDBUS0)
FTDI_USB_N: U1.7 (DM); also elsewhere on the board
FTDI_USB_P: U1.8 (DP); also elsewhere on the board
GND: C72.2, C74.2, C76.2, C78.2, C79.2, C80.2, C81.2, C82.2, C83.2, C84.2, C85.2, C86.2, C87.2, R59.1, U1.10 (TEST), U1.21 (GND), U1.41 (GND), U1.45 (GND), U1.54 (PWREN), U1.57 (GND), U11.5 (GND), Y4.2, Y4.4; also elsewhere on the board
unnamed: C83.1, U1.3 (OSCI), Y4.1
unnamed: C84.1, U1.4 (OSCO), Y4.3
unnamed: R55.1, U1.1 (EECS), U11.1 (CS)
unnamed: R56.1, U11.4 (DO)
unnamed: R56.2, R58.1, U1.55 (EEDATA), U11.3 (DI)
unnamed: R57.1, U1.56 (EECLK), U11.2 (SCLK)
unnamed: R59.2, U1.6 (REF)
unnamed: R60.1, U1.11 (RESET)
SWCLK: R73.2; also elsewhere on the board
SWDIO: R74.2; also elsewhere on the board
nRF_RST: U1.17 (ADBUS4); also elsewhere on the board
nRF_RX: R71.2; also elsewhere on the board
nRF_TX: R72.2; also elsewhere on the board

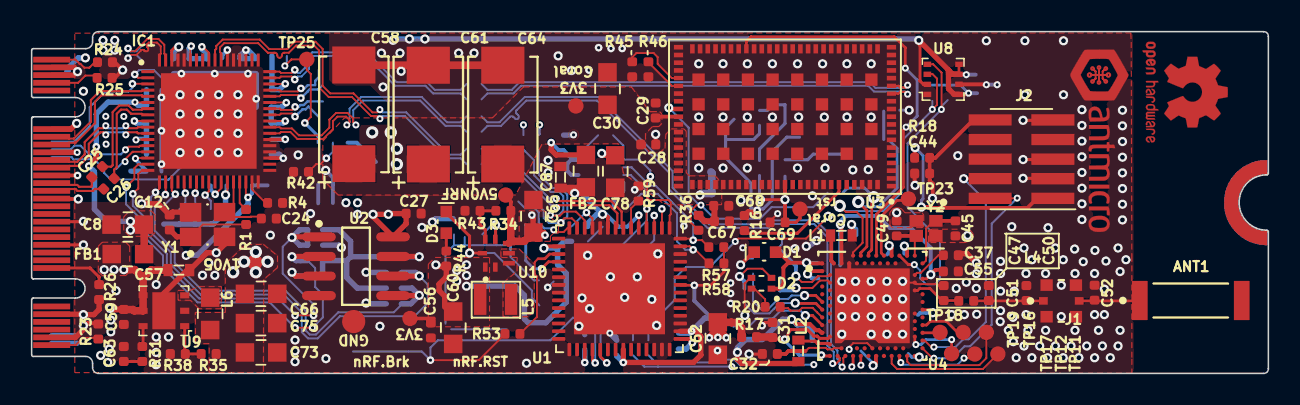
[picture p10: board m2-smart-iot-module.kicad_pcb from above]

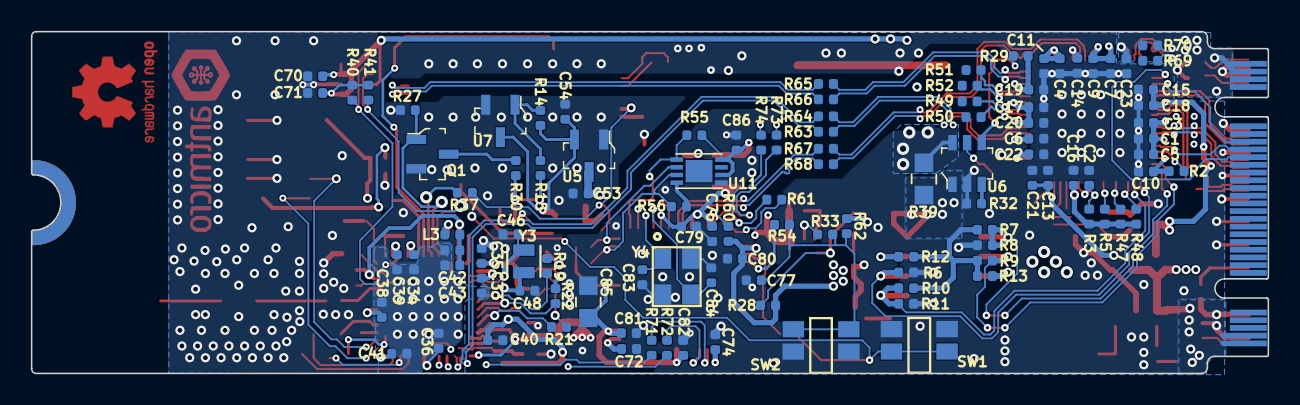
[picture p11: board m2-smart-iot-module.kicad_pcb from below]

Board: 4 copper layers, 80.1 x 22.2 mm, 212 parts (109 on the bottom side), 135 nets.

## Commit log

2021-08-11 Add PCIe/USB controller
    [antmicro-pcie-radio-module.kicad_pcb, antmicro-pcie-radio-module.sch, pcie-usb-bridge.sch]
2021-08-11 Add initial mechanical mock
    [antmicro-pcie-radio-module.kicad_pcb, antmicro-pcie-radio-module.sch, pcie-usb-bridge.sch]
2021-08-11 Add M.2 B+M edge connector
    [M2-Pins.sch, antmicro-pcie-radio-module.kicad_pcb, antmicro-pcie-radio-module.sch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]
2021-08-11 Initial work on RF part
    [M2-Pins.sch, antmicro-pcie-radio-module.kicad_pcb, antmicro-pcie-radio-module.sch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]
2021-08-11 Update U.FL model, fix library links
    [antmicro-pcie-radio-module.kicad_pcb]
2021-08-11 Add IOs
    [coralAccelerator.sch, nRF52840.sch, pcie-usb-bridge.sch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]
2021-08-11 Add power supply circuitry
    [nRF52840.sch, powerSupply.sch]
2021-08-11 Finishing schematics, RF part left
    [M2-Pins.sch, nRF52840.sch, pcie-usb-bridge.sch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]
2021-08-11 Add RF path
    [M2-Pins.sch, coralAccelerator.sch, nRF52840.sch]
2021-08-11 Add initial component layout
    [M2-Pins.sch, antmicro-pcie-radio-module.kicad_pcb, coralAccelerator.sch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]
2021-08-11 Layout: add signal traces
    [antmicro-pcie-radio-module.kicad_pcb, nRF52840.sch]
2021-08-11 Layout: add power planes
    [antmicro-pcie-radio-module.kicad_pcb]
2021-08-11 Resolve DRC
    [M2-Pins.sch, antmicro-pcie-radio-module.kicad_pcb, antmicro-pcie-radio-module.sch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]
2021-08-11 Add changes after pre-production review.
    [M2-Pins.sch, antmicro-pcie-radio-module.kicad_pcb, antmicro-pcie-radio-module.sch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]
2021-08-11 Add BME280
    [antmicro-pcie-radio-module.kicad_pcb, nRF52840.sch]
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2022-03-18 Cleaned first 3 schematic sheets; Started fixing schematics after rev 1.0.0 bringup
    [M2-Pins.sch, coralAccelerator.sch, nRF52840.sch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]
2022-03-21 Added Coral RESET circuitry
    [coralAccelerator.sch, nRF52840.sch, powerSupply.sch]
2022-03-22 Changed DCDC converter to available ones
    [powerSupply.sch]
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2022-03-22 Fixed USBSEL pullup, missing connection on DCDC cap
    [coralAccelerator.sch, powerSupply.sch]
2022-03-22 Routed PCIe, rev bumped to 1.1.0
    [M2-Pins.sch, m2-smart-iot-module.kicad_pcb, m2-smart-iot-module.sch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]
2022-03-25 Finish routing - no unconnected nets, DRC almost clear
    [m2-smart-iot-module.kicad_pcb]
2022-03-25 Route R16 (change from schematic)
    [m2-smart-iot-module.kicad_pcb]
2022-03-25 Designator cleanup, update revision info
    [m2-smart-iot-module.kicad_pcb]
2022-03-28 Labels position corrections
    [m2-smart-iot-module.kicad_pcb]
2022-03-29 Added 0R DNP to pins 49, 50.
    [coralAccelerator.sch]
2022-03-29 Rearrangement of JTAG connector and U8 sensor
    [m2-smart-iot-module.kicad_pcb]
2022-03-29 Moved antenna out of GND plane
    [m2-smart-iot-module.kicad_pcb]
2022-03-30 Updated width and gap of USB and PCIe lanes to correct impedance
    [coralAccelerator.sch, m2-smart-iot-module.kicad_pcb]
2022-03-30 Added stackup table to PCB
    [m2-smart-iot-module.kicad_pcb]
2022-03-31 Added spreadsheet with power consumption
    [power_consumption.ods]
2022-03-31 Added 3d models of BME280 and 1V05 DCDC
    [coralAccelerator.sch, m2-smart-iot-module.kicad_pcb]
2022-04-07 Silkscreen improvements, removed DRC errors on M.2 connector
    [m2-smart-iot-module.kicad_pcb]
2022-04-07 Adjust position of C56, add GND via near C56 and C60
    [m2-smart-iot-module.kicad_pcb]
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2022-07-11 Added comments to schematic
    [ftdi.kicad_sch, m2-smart-iot-module.kicad_pcb, nRF52840.kicad_sch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]
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2022-07-11 Moved button to bottom
    [m2-smart-iot-module.kicad_pcb]
2022-07-11 Bumped version to 1.2.1
    [M2-Pins.kicad_sch, coralAccelerator.kicad_sch, ftdi.kicad_sch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]
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2022-07-11 Bumped version to 1.2.2
    [M2-Pins.kicad_sch, coralAccelerator.kicad_sch, ftdi.kicad_sch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]
2022-07-12 Fixed SWD
    [ftdi.kicad_sch, m2-smart-iot-module.kicad_pcb, m2-smart-iot-module.kicad_sch]
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2022-07-12 Cleanup, fix ignore
    [power_consumption.ods]
2022-07-15 Applied fixes to issues that came up in review
    [ftdi.kicad_sch, m2-smart-iot-module.kicad_pcb, m2-smart-iot-module.kicad_sch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]
2022-07-15 Bumped version to 1.2.4
    [M2-Pins.kicad_sch, coralAccelerator.kicad_sch, ftdi.kicad_sch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]
2022-08-19 Fixed silkscreen
    [m2-smart-iot-module.kicad_pcb]
2022-08-19 Cleanup old version files
    [M2-Pins.sch, coralAccelerator.sch, m2-smart-iot-module.sch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]
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2022-08-19 Fix DRC
    [m2-smart-iot-module.kicad_pcb]
2022-08-19 Bump revision to 1.2.5
    [M2-Pins.kicad_sch, coralAccelerator.kicad_sch, ftdi.kicad_sch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]
2022-08-19 Place NRF52 reset via in empty space between AC9 and AC5
    [m2-smart-iot-module.kicad_pcb]
2022-08-19 Bump revision to 1.2.6
    [M2-Pins.kicad_sch, coralAccelerator.kicad_sch, ftdi.kicad_sch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]
2022-08-19 Replaced ft2232 with ft4232H
    [ftdi.kicad_sch, m2-smart-iot-module.kicad_pcb, m2-smart-iot-module.kicad_sch]
2022-08-19 Bump revision to 1.2.7
    [M2-Pins.kicad_sch, coralAccelerator.kicad_sch, ftdi.kicad_sch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]
2022-08-19 Migrated Project Symobl Library to KiCad6 format
    The old KiCad 5.x project libraries in conjunction with KiCad 6 project files
    cause kmake bom and others to fail and throw errors
2022-08-19 Ported to pcbway stackup
    [m2-smart-iot-module.kicad_pcb]
2022-08-19 Rev bump to 1.2.8
    [M2-Pins.kicad_sch, coralAccelerator.kicad_sch, ftdi.kicad_sch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]
2022-08-19 Add OR resistors to outputs of the PCIE-USB bridge and FTDI
    [ftdi.kicad_sch, m2-smart-iot-module.kicad_sch, pcie-usb-bridge.kicad_sch]
2022-08-19 Add resistors to PCB, adjust routing, clear silks
    [m2-smart-iot-module.kicad_pcb]
2022-08-19 Bump revision to 1.2.9
    [M2-Pins.kicad_sch, coralAccelerator.kicad_sch, ftdi.kicad_sch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]
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2026-08-04 [#102286] Bump to KiCad10
    [M2-Pins.kicad_sch, coralAccelerator.kicad_sch, ftdi.kicad_sch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]
2026-08-04 [#102286] Fix legacy DNP
    [M2-Pins.kicad_sch, coralAccelerator.kicad_sch, m2-smart-iot-module.kicad_pcb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]
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2026-08-06 [#102286] Set exclude from BOM & pnp for J3
    [M2-Pins.kicad_sch]
2026-08-06 [#102286] Set exclude from BOM & pnp for MP1
    [m2-smart-iot-module.kicad_sch]
2026-08-06 [#102286] Add pnp override
    [board-override.csv]
2026-08-06 [#102286] Unify C_100n_0402 capacitors to use single MPN
    Refs: C1, C3, C6, C7, C10, C13, C17, C18, C25-C29, C33, C36, C39, C41,
    C44, C67-C71
    Change from 0402X104K6R3CT to GRM155R61H104KE14D (same but limit 50V
    instead of 6V3)
    [coralAccelerator.kicad_sch, nRF52840.kicad_sch, pcie-usb-bridge.kicad_sch]
2026-08-06 [#102286] Add user 9
    [m2-smart-iot-module.kicad_pcb]
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2026-08-10 [#102286] Fix U3 override rotation
    [board-override.csv]
2026-08-14 [#102286] Update footprint names in overrides
    [board-override.csv]
2026-08-17 [#102286] Set MPN & MFR in U11
    [ftdi.kicad_sch, powerSupply.kicad_sch]
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2026-08-18 [#102286] Update overrides with markings
    [board-override.csv]
2026-08-18 [#102286] Rotate PCB 180*
    [M2-Pins.kicad_sch, coralAccelerator.kicad_sch, ftdi.kicad_sch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]
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
